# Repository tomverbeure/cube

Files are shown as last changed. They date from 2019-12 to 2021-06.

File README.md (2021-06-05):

# LED Cube with Cisco Controller and Pixel Purse LED Panels

This repo needs a bit of cleanup for general public consumption,
but it had all the assets for my LED cube that’s built from
[Project MC2 Pixel Purse LED panels](https://tomverbeure.github.io/2019/10/03/Pixel-Purse.html) 
and a [Cisco HWIC-3G-CDMA modem](https://tomverbeure.github.io/2019/11/11/Cisco-HWIC-3G-CDMA.html).

I gave a talk about this project at BangBangCon West 2020: here are
the [video](https://www.youtube.com/watch?v=0tBU5-lJYmU) and [slides](https://docs.google.com/presentation/d/1FYmVh-brx6SpZoJmzuIXrNegWdtriQ9k38EbrvDupg8) of the talk.

I also wrote a [blog post](https://tomverbeure.github.io/2021/05/16/Pixel-Purse-LED-Cube.html)
about this project.

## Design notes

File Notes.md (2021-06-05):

## Current Measurements:

* 3.3V

0:

* All LEDs off: 0.6A

255:

* All LEDs red: 6.6A
* All LEDs green: 3.6A
* All LEDs blue: 2.8A

* All LEDs red + green: 6.8A
* All LEDs red + blue: 6.5A
* All LEDs green + blue: 4.2A

* All LEDs green + green + blue: 7.8A

128: (with gamma!)

* All LEDs red: 2.2A
* All LEDs green: 1.3A
* All LEDs blue: 1.2A

* All LEDs red + green: 2.5A
* All LEDs red + blue: 2.3A
* All LEDs green + blue: 1.6A

* All LEDs green + green + blue: 2.4A

64: (with gamma!)

* All LEDs red: 1.0A
* All LEDs green: 0.8A
* All LEDs blue: 0.7A

* All LEDs red + green: 1.1A
* All LEDs red + blue:
* All LEDs green + blue: 

* All LEDs green + green + blue: 1.1A

## LED Addressing

### LED Memory Physical Address map

LED mem has 2 buffers (for double-buffered rendering).
Each buffer has a size of 6 * 32 * 32 = 6144 words, so the total LED memory is 12288 words.

In LED mem, each side of the cube has a rectangle assigned to them.

The sides are numbered as follows:
   
```
    +---+
    | 4 |     
+---+---+---+---+
| 0 | 1 | 2 | 3 |
+---+---+---+---+
    | 5 |     
    +---+
```

Within a buffer, addressing is as follows:

* start address of each side is `side_nr * 32 * 32`
* start address corresponds to the top-left of each square above
* the pitch of each side is the same as the number of columns.

The corresponding naming convention: left, front, right, back, top, bottom.

```
    +---+
    | T |     
+---+---+---+---+
| L | F | R | Ba|
+---+---+---+---+
    | Bo|     
    +---+
```

The Hub75Streamer block has a `PANEL_INFO` registers that contains all the information to
translate from the LED mem addressing. If panels are rotated, it can compensate for that.

### LED Memory Locial Address Maps

To make life for the CPU easier, there are also logical address maps, which are
designed such that there is an intuitive overflow behavior wrt neighboring tile.

There is one logical map for each 'infinite ring', where, if you continue in the same
primary direction, you end up in the same place as before in a logical way.

Here is one such example:

```
+---+---+---+---+---+---+
| T | T | T | T | T | T |   
+---+---+---+---+---+---+
| L | F | R | Ba| L | F |
+---+---+---+---+---+---+
| Bo| Bo| Bo| Bo| Bo| Bo|
+---+---+---+---+---+---+
```

In this case, the ring consists of tile L-F-R-B. T and B are considered non-ring
overflow tiles.

When you start on the left side and keep in increasing the X coordinate, you'll wrap around
the cube and end up in the same place after 4 side.

The image above is laid out on a rectangular logical address map, with a pitch that is at least
6 wide. But it's easier to make it 8 wide, so it will look a bit like this:

```
+---+---+---+---+---+---+---+---+
| T | T | T | T | T | T | T | T |
+---+---+---+---+---+---+---+---+
| L | F | R | Ba| L | F | R | Ba|
+---+---+---+---+---+---+---+---+
| Bo| Bo| Bo| Bo| Bo| Bo| Bo| Bo|
+---+---+---+---+---+---+---+---+
```

With the arrangement above, you can blit any image that is 32 pixels height and up to
5 sides wide at any starting point of the ring and have correct roll-over behavior.
Since it makes no sense to have a image that's more than 4 sides wide (because the right
would overwrite the left), that's fine.

For the case above, the top and the bottom tiles will have different overflow
behavior for each for the 4 members of the ring. For example if you are in L and
you go up until you roll over into tile T, then the L(X,Y) coordinate converts into
T(X, Y). However, if you in F and you do the same thing, then F(X,Y) converts
into T(32-Y,X).

Here are different rings: 

F-Bo-Ba-T:

```
+---+---+---+---+---+---+---+---+
| R | R | R | R | R | R | R | R |
+---+---+---+---+---+---+---+---+
| F | Bo| Ba| T | F | Bo| Ba| T |
+---+---+---+---+---+---+---+---+
| L | L | L | L | L | L | L | L |
+---+---+---+---+---+---+---+---+
```

L-Bo-R-T:

```
+---+---+---+---+---+---+---+---+
| Ba| Ba| Ba| Ba| Ba| Ba| Ba| Ba|
+---+---+---+---+---+---+---+---+
| L | Bo| R | T | L | Bo| R | T |
+---+---+---+---+---+---+---+---+
| F | F | F | F | F | F | F | F |
+---+---+---+---+---+---+---+---+
```

Calculation for:

| L | F | R | Ba| L | F | R | Ba|

Given an address for a particular ring:

```
strip_size = 16 * 32 * 32
side_size  = 32 * 32

strip_y_nr = addr / strip_size
strip_x_nr = (addr % strip_size) / side_size

strip_class = [ L, F, R, Ba ][strip_x_nr & 3]
if (strip_y_nr == 0) 
    side_nr = T
    orient_class = { 
                     L  -> (32-X, Y),
                     F  -> (X, Y),  
                     R  -> (32-Y, X),
                     Ba -> (32-X, Y)
                   }[strip_class]
                     
else if (strip_y_nr == 1) 
    side_nr = strip_class
    orient_class = (X,Y)

else if (strip_y_nr == 2)
    side_nr = Bo
    orient_class = { 
                     L  -> (32-X, Y),
                     F  -> (X, Y),  
                     R  -> (32-Y, X),
                     Ba -> (32-X, Y)
                   }[strip_class]

led_mem_addr = (side_nr * 32 * 32) + orient_class[1] * 32 + orient_class[0]
```

Each ring occupies 8 x 3 = 24 sides, but we allocate 32 sides for that.
That gives 32 * 32 * 32 = 32k addresses per ring.
There are 3 rings, so we need 98k local addresses.

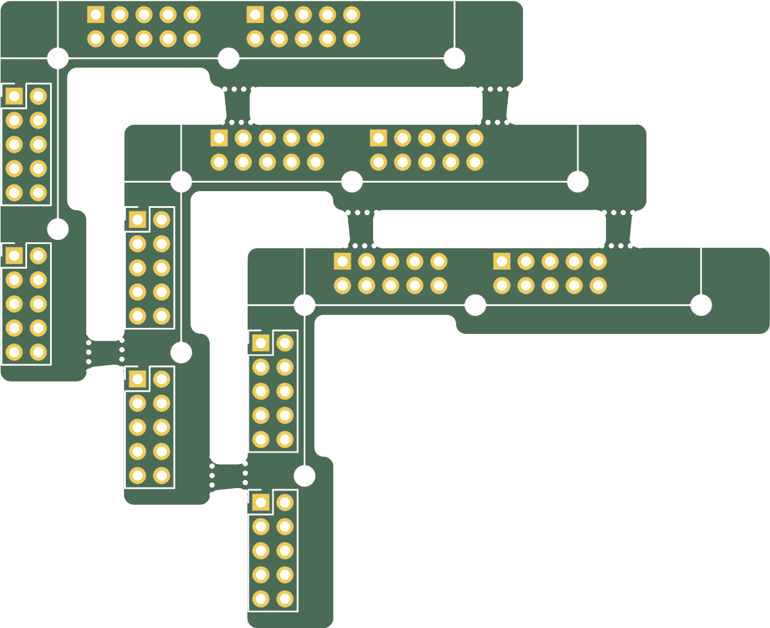
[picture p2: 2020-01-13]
pcbs/frame_corners/panelized/upload1/Untitled_Combined_Top.png

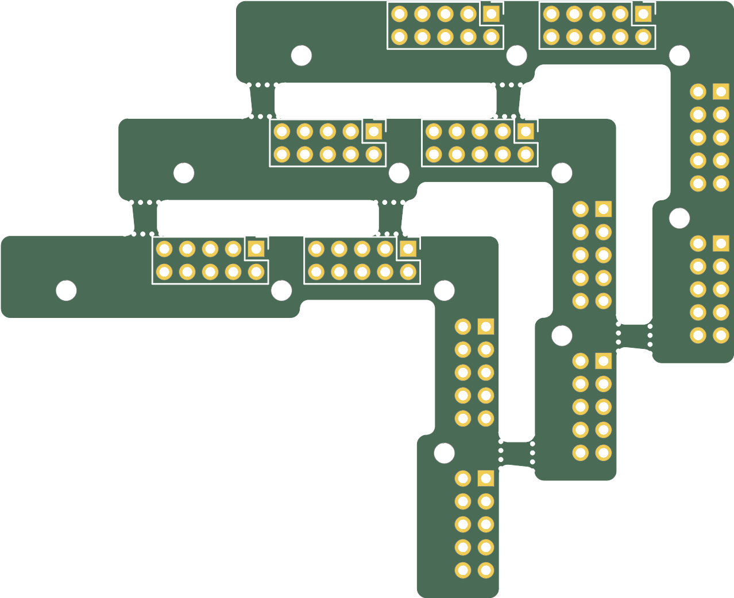
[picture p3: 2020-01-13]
pcbs/frame_corners/panelized/upload1/Untitled_Combined_Bottom.png

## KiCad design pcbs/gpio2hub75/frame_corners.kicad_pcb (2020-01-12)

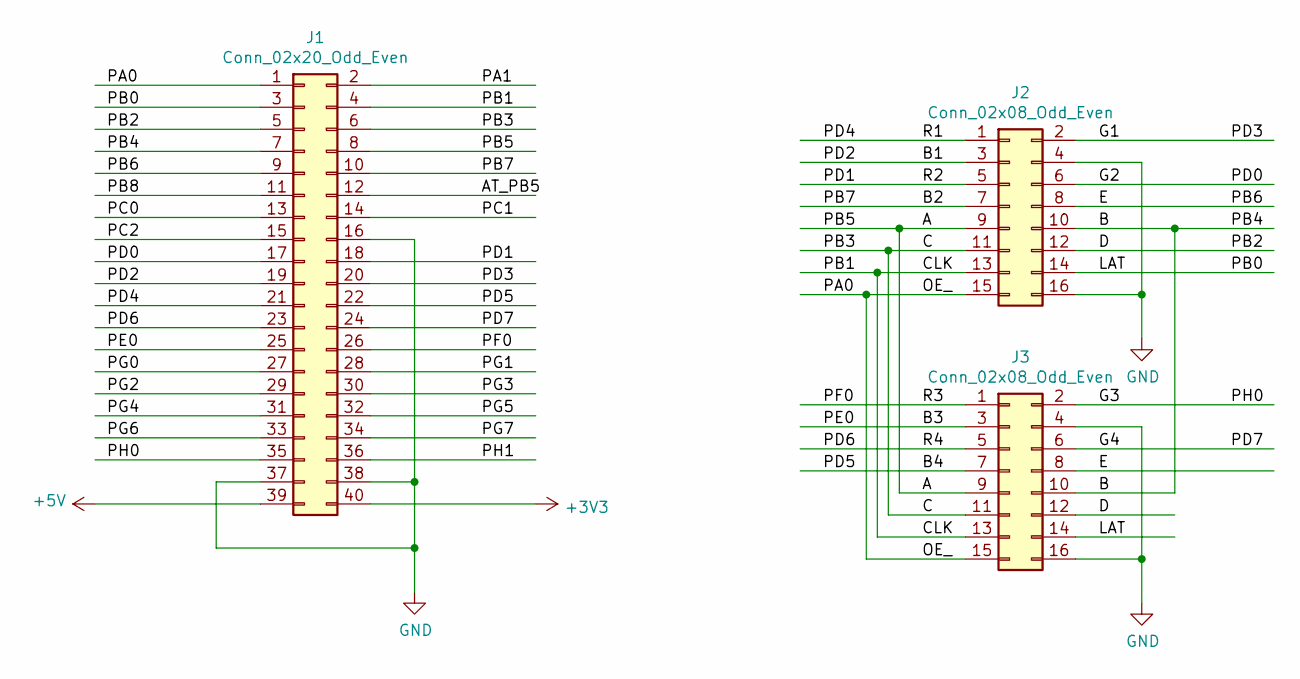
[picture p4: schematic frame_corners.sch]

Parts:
J1: Conn_02x20_Odd_Even; PinSocket_2x20_P2.54mm_Horizontal
J2, J3: Conn_02x08_Odd_Even; PinHeader_2x08_P2.54mm_Vertical

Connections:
+3V3: J1.40
+5V: J1.39
/A: J1.8, J2.9, J3.9
/AT_PB5: J1.12
/B: J1.7, J2.10, J3.10
/B1: J1.19, J2.3
/B2: J1.10, J2.7
/B3: J1.25, J3.3
/B4: J1.22, J3.7
/C: J1.6, J2.11, J3.11
/CLK: J1.4, J2.13, J3.13
/D: J1.5, J2.12, J3.12
/E: J1.9, J2.8, J3.8
/G1: J1.20, J2.2
/G2: J1.17, J2.6
/G3: J1.35, J3.2
/G4: J1.24, J3.6
/LAT: J1.3, J2.14, J3.14
/OE_: J1.1, J2.15, J3.15
/PA1: J1.2
/PB8: J1.11
/PC0: J1.13
/PC1: J1.14
/PC2: J1.15
/PD1: J1.18, J2.5
/PD4: J1.21, J2.1
/PD6: J1.23, J3.5
/PF0: J1.26, J3.1
/PG0: J1.27
/PG1: J1.28
/PG2: J1.29
/PG3: J1.30
/PG4: J1.31
/PG5: J1.32
/PG6: J1.33
/PG7: J1.34
/PH1: J1.36
GND: J1.16, J1.37, J1.38, J2.4, J2.16, J3.4, J3.16

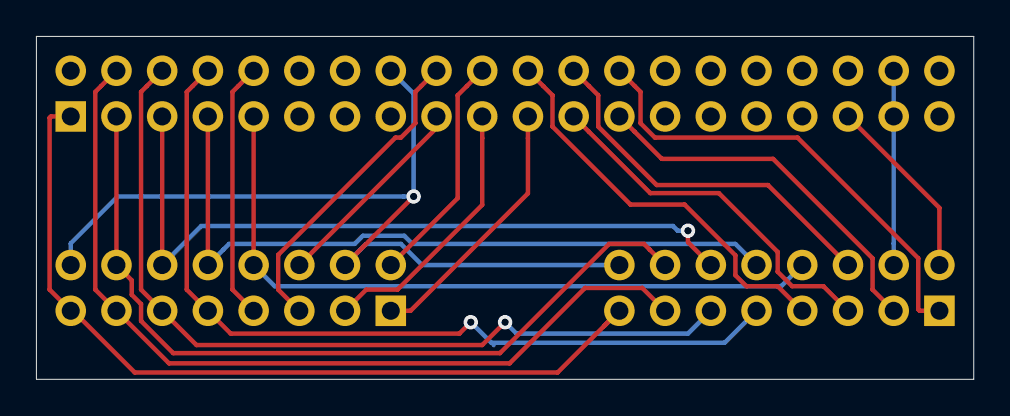
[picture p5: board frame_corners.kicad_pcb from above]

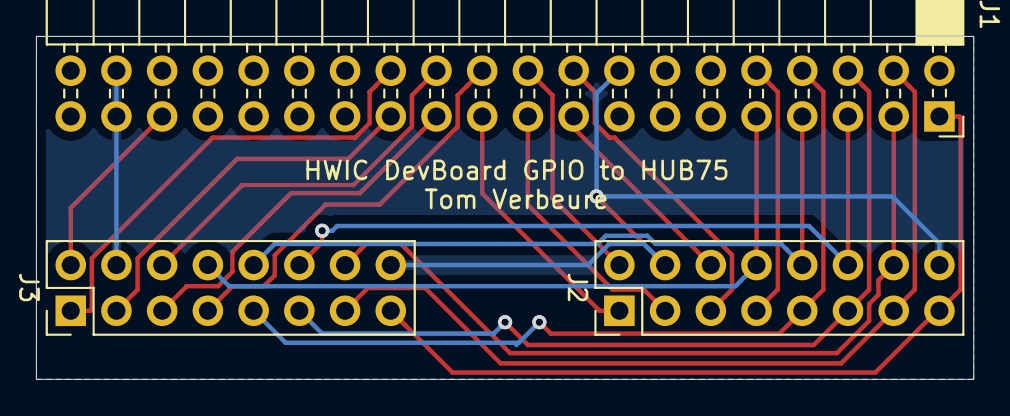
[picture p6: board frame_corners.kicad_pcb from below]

Board: 2 copper layers, 52.1 x 19.1 mm, 3 parts (3 on the bottom side), 21 nets.

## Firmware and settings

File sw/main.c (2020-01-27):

#include <stdint.h>

#include "reg.h"
#include "top_defines.h"
//#include "led_render.h"
#include "hub75_streamer.h"

#include "../movie/palette.h"
#include "../movie/ricks_compr.h"

static inline uint32_t rdcycle(void) {
    uint32_t cycle;
    asm volatile ("rdcycle %0" : "=r"(cycle));
    return cycle;
}

static inline int nop(void) {
    asm volatile ("addi x0, x0, 0");
    return 0;
}

void wait(int cycles)
{
#if 1
    volatile int cnt = 0;

    for(int i=0;i<cycles/20;++i){
        ++cnt;
    }
#else
    int start;

    start = rdcycle();
    while ((rdcycle() - start) <= cycles);
#endif
}


uint16_t pacman_closed[11] = {
    0b00011111000,
    0b00111111100,
    0b01111111110,
    0b11111111111,
    0b11111111111,
    0b11111111111,
    0b11111111111,
    0b11111111111,
    0b01111111110,
    0b00111111100,
    0b00011111000,
};

uint16_t pacman_open[11] = {
    0b00011111000,
    0b00111111100,
    0b01111111110,
    0b00011111111,
    0b00000111111,
    0b00000001111,
    0b00000111111,
    0b00011111111,
    0b01111111110,
    0b00111111100,
    0b00011111000,
};

uint16_t pacman_test[11] = {
    0b10000000000,
    0b11000000000,
    0b10100000000,
    0b10010000000,
    0b10001000000,
    0b10000100000,
    0b10000010000,
    0b10000001000,
    0b10000000100,
    0b10000000010,
    0b10000000001,
};

uint32_t ghost_left_0[14] = {
    0b0000000000010101010000000000,
    0b0000000101010101010101000000,
    0b0000010101010101010101010000,
    0b0001010101010101010101010100,
    0b0001010111110101010111110100,
    0b0001011111111101011111111100,
    0b0101011111101001011111101001,
    0b0101011111101001011111101001,
    0b0101010111110101010111110101,
    0b0101010101010101010101010101,
    0b0101010101010101010101010101,
    0b0101010101010101010101010101,
    0b0101010100010101010001010101,
    0b0001010000000101000000010100,
};

uint32_t ghost_left_1[14] = {
    0b0000000000010101010000000000,
    0b0000000101010101010101000000,
    0b0000010101010101010101010000,
    0b0001010101010101010101010100,
    0b0001010111110101010111110100,
    0b0001011111111101011111111100,
    0b0101011111101001011111101001,
    0b0101011111101001011111101001,
    0b0101010111110101010111110101,
    0b0101010101010101010101010101,
    0b0101010101010101010101010101,
    0b0101010101010101010101010101,
    0b0101000101010000010101000101,
    0b0100000001010000010100000001,
};


uint32_t ghost_up_0[14] = {
    0b0000000000010101010000000000,
    0b0000001010010101011010000000,
    0b0000111010110101111010110000,
    0b0001111111110101111111110100,
    0b0001111111110101111111110100,
    0b0001011111010101011111010100,
    0b0101010101010101010101010101,
    0b0101010101010101010101010101,
    0b0101010101010101010101010101,
    0b0101010101010101010101010101,
    0b0101010101010101010101010101,
    0b0101010101010101010101010101,
    0b0101010100010101010001010101,
    0b0001010000000101000000010100,
};

uint32_t ghost_up_1[14] = {
    0b0000000000010101010000000000,
    0b0000001010010101011010000000,
    0b0000111010110101111010110000,
    0b0001111111110101111111110100,
    0b0001111111110101111111110100,
    0b0001011111010101011111010100,
    0b0101010101010101010101010101,
    0b0101010101010101010101010101,
    0b0101010101010101010101010101,
    0b0101010101010101010101010101,
    0b0101010101010101010101010101,
    0b0101010101010101010101010101,
    0b0101000101010000010101000101,
    0b0100000001010000010100000001,
};

uint32_t ghost_down_0[14] = {
    0b0000000000010101010000000000,
    0b0000000101010101010101000000,
    0b0000010101010101010101010000,
    0b0001010101010101010101010100,
    0b0001011111010101011111010100,
    0b0001111111110101111111110100,
    0b0101111111110101111111110101,
    0b0101111010110101111010110101,
    0b0101011010010101011010010101,
    0b0101010101010101010101010101,
    0b0101010101010101010101010101,
    0b0101010101010101010101010101,
    0b0101010100010101010001010101,
    0b0001010000000101000000010100,
};

uint32_t ghost_down_1[14] = {
    0b0000000000010101010000000000,
    0b0000000101010101010101000000,
    0b0000010101010101010101010000,
    0b0001010101010101010101010100,
    0b0001011111010101011111010100,
    0b0001111111110101111111110100,
    0b0101111111110101111111110101,
    0b0101111010110101111010110101,
    0b0101011010010101011010010101,
    0b0101010101010101010101010101,
    0b0101010101010101010101010101,
    0b0101010101010101010101010101,
    0b0101000101010000010101000101,
    0b0100000001010000010100000001,
};



uint32_t ghost_scared_0[14] = {
    0b0000000000010101010000000000,
    0b0000000101010101010101000000,
    0b0000010101010101010101010000,
    0b0001010101010101010101010100,
    0b0001010101010101010101010100,
    0b0001010111110101111101010100,
    0b0101010111110101111101010101,
    0b0101010101010101010101010101,
    0b0101010101010101010101010101,
    0b0101111101011111010111110101,
    0b0111010111110101111101011101,
    0b0101010101010101010101010101,
    0b0101000101010000010101000101,
    0b0100000001010000010100000001,
};


uint32_t cherry[12] = {
    0b000000000000000000001010,
    0b000000000000000010101010,
    0b000000000000101000100000,
    0b000000000010000000100000,
    0b000101011000000010000000,
    0b010101100101001000000000,
    0b010101010100011001010000,
    0b011101010001011001010100,
    0b010111010001010101010100,
    0b000101010001110101010100,
    0b000000000001011101010100,
    0b000000000000010101010000,
};

uint16_t dot_small[2] = {
    0b11,
    0b11,
};

uint16_t dot_large[8] = {
    0b00111100,
    0b01111110,
    0b11111111,
    0b11111111,
    0b11111111,
    0b11111111,
    0b01111110,
    0b00111100,
};

uint32_t mario_ground[3] = {
    0b01111111111111111110011111111101,
    0b11010101010101010110110101010110,
    0b11010101010101010110111001010110
};

uint32_t mario_ground_colors[4] = { 0x000000, 0x1556d0, 0x000000, 0xc1c2f7 };

uint32_t mario_sky_color = 0xff8f58;


uint32_t mario_walk_0[16] = {
    0b00000000001010101010000000000000,
    0b00000000101010101010101010000000,
    0b00000000010101111101110000000000,
    0b00000001110111111101111111000000,
    0b00000001110101111111011111110000,
    0b00000001011111111101010101000000,
    0b00000000001111111111111100000000,
    0b00000101010110100101000000000000,
    0b11110101010110101001010111111100,
    0b11111100010110111010100101111100,
    0b11110000101010101010100000010000,
    0b00000010101010101010101001010000,
    0b00001010101010101010101001010000,
    0b00010110101000000010101001010000,
    0b00010101000000000000000000000000,
    0b00000101010000000000000000000000,
};

uint32_t mario_walk_1[16] = {
    0b00000000001010101010000000000000,
    0b00000000101010101010101010000000,
    0b00000000010101111101110000000000,
    0b00000001110111111101111111000000,
    0b00000001110101111111011111110000,
    0b00000001011111111101010101000000,
    0b00000000001111111111111100000000,
    0b00000000010110010101000000000000,
    0b00000001010101101001010000000000,
    0b00000001010110101110101100000000,
    0b00000001010101101010101000000000,
    0b00000010010111111110101000000000,
    0b00000000100111111010100000000000,
    0b00000000001010100101010000000000,
    0b00000000000101010101010100000000,
    0b00000000000101010100000000000000,
};

uint32_t mario_walk_2[16] = {
    0b00000000000000000000000000000000,
    0b00000000000010101010100000000000,
    0b00000000001010101010101010100000,
    0b00000000000101011111011100000000,
    0b00000000011101111111011111110000,
    0b00000000011101011111110111111100,
    0b00000000010111111111010101010000,
    0b00000000000011111111111111000000,
    0b00000000000101010110010011000000,
    0b00000000110101010101011111110000,
    0b00000011111001010101011111000000,
    0b00000001011010101010101000000000,
    0b00000001101010101010101000000000,
    0b00000101101010001010100000000000,
    0b00000100000000010101000000000000,
    0b00000000000000010101010000000000,
};


uint32_t mario_colors[4] = { 0x000000, 0x106d8a, 0x053bec, 0x3d9fff };


uint32_t pac_color = 0x36fffe;

uint32_t ghost_pink_colors[4]    = { 0x000000, 0xcb98ff, 0xff0000, 0xffffff };
uint32_t ghost_cyan_colors[4]    = { 0x000000, 0xfffe2c, 0xff0000, 0xffffff };
uint32_t ghost_red_colors[4]     = { 0x000000, 0x0711ff, 0xff0000, 0xffffff };
uint32_t ghost_orange_colors[4]  = { 0x000000, 0x42cfff, 0xff0000, 0xffffff };
uint32_t ghost_scared_colors[4]  = { 0x000000, 0xfb1313, 0x000000, 0x42cfff };

uint32_t cherry_colors[4]        = { 0x000000, 0x0711ff, 0x5599de, 0xffffff };

uint32_t border_color = 0xfb0022;

uint32_t dot_color = 0x92b1f8;


#define WAIT_CYCLES 4000000

void led_mem_wr(int buffer_nr, int side, int x, int y, unsigned char r, unsigned char g, unsigned char b)
{
        MEM_WR(LED_MEM, buffer_nr * 6 * 32 * 32 + side * 32 * 32 + y*32 + x, r | (g<<8) | (b<<16));
}

void led_mem_fill(int buffer_nr, unsigned char r, unsigned char g, unsigned char b)
{
    for(int side = 0; side < 6; ++side){
	    for(int row=0;row<32;++row){
	        for(int col=0;col<32;++col){
	            led_mem_wr(buffer_nr, side, col, row, r, g, b);
	        }
	    }
    }
}

void led_mem_clear(int buffer_nr)
{
    led_mem_fill(buffer_nr, 0, 0, 0);
}

void led_mem_effect(int buffer_nr)
{
    unsigned char r,g,b;

    for(r=0;r<255;++r){
        for(g=0;g<255;++g){
            for(b=0;b<255;++b){
                led_mem_fill(buffer_nr, r,g,b);
            }
        }
    }
}

void led_mem_stripes(int buffer_nr)
{
    for(int side = 0; side < 6; ++side){
	    for(int row=0;row<32;++row){
	        for(int col=0;col<32;++col){
	            led_mem_wr(buffer_nr, side, col, row, 
	                            (col % 3) == 0 ? 255 : 0, 
	                            (col % 3) == 1 ? 255 : 0, 
	                            (col % 3) == 2 ? 255 : 0);
	        }
	    }
    }
}

void led_mem_stripes_rick()
{

    for(int frame_nr = 0; frame_nr < 16; ++frame_nr){

        unsigned char *ptr = ricks_compr_bin + frame_nr * 32 * 23;

        for(int row=0; row<23; ++row){
            for(int col=0;col<32;col+=2){
                if (col == frame_nr*2){
                    ptr[row * 32 + col] = 10;
                }
                else{
                    ptr[row * 32 + col] = 0;
                }
            }
        }
    }
}

void led_mem_rows(int buffer_nr)
{
    for(int side=0; side<6; side++){
	    for(int row=0;row<32;++row){
	        for(int col=0;col<32;++col){
	            if (col<10){
	                led_mem_wr(buffer_nr, side, col, row, row*7, 0, 0);
	            } 
	            else if (col<20){
	                led_mem_wr(buffer_nr, side, col, row, 0, row*7, 0);
	            }
	            else if (col<30){
	                led_mem_wr(buffer_nr, side, col, row, 0, 0, row*7);
	            }
	            else{
	                led_mem_wr(buffer_nr, side, col, row, 0, row*7, row*7);
	            }
	        }
	    }
    }
}

void led_mem_rick(int buffer_nr, int frame_nr)
{

    for(int side = 0; side < 6; ++side){

        int frame_nr_adj = (frame_nr + side) % 16;
        unsigned char *ptr = ricks_compr_bin + frame_nr_adj * (32/2) * 23;

	    for(int row=0; row<32; ++row){
	        for(int col=0;col<32;col+=2){
	            if (row < 4 || row >= 27){
	                led_mem_wr(buffer_nr, side, col, row, side == 0 || side == 3 ? 32 : 0, side == 1 || side == 4 ? 32 : 0 , side == 2 || side == 5 ? 32 : 0);
	            }
	            else{
	                unsigned char val = *ptr;

	                led_mem_wr(buffer_nr, side, col, row, 
	                                palette_bin[(val & 15) * 3],
	                                palette_bin[(val & 15) * 3 + 1],
	                                palette_bin[(val & 15) * 3 + 2]);

	                led_mem_wr(buffer_nr, side, col+1, row, 
	                                palette_bin[(val>>4) * 3],
	                                palette_bin[(val>>4) * 3 + 1],
	                                palette_bin[(val>>4) * 3 + 2]);
	                ++ptr;
	            }
	
	        }
	    }
    }
}

void render_bitmap_1bpp(uint16_t *bitmap, uint32_t color, int size_x, int size_y, int buffer_nr, e_hub75_ring ring, int pos_x, int pos_y)
{
    for(int y=0; y<size_y;++y){
        for(int x=0; x<size_x;++x){
                //uint32_t bit = (bitmap[y] >> (size_x-1-x)) & 1;
                uint32_t bit = (bitmap[y] >> (x)) & 1;
                if (!bit)
                    continue;

                uint32_t log_addr = ring * HUB75S_RING_SIZE 
                                    + ((pos_y+y) + HUB75S_SIDE_HEIGHT) * HUB75S_STRIP_WIDTH 
                                    + (pos_x+x);
                    
                uint32_t phys_addr = hub75s_calc_phys_addr(buffer_nr, log_addr);

                MEM_WR(LED_MEM, phys_addr, color);
        }
    }
}

void render_bitmap_2bpp(uint32_t *bitmap, uint32_t *colors, int size_x, int size_y, int buffer_nr, e_hub75_ring ring, int pos_x, int pos_y)
{
    for(int y=0; y<size_y;++y){
        for(int x=0; x<size_x;++x){
                //uint32_t bit = (bitmap[y] >> (size_x-1-x)) & 1;
                uint32_t bits = (bitmap[y] >> (2*size_x-2 - 2*x)) & 3;
                if (bits == 0)
                    continue;

                uint32_t log_addr = ring * HUB75S_RING_SIZE 
                                    + ((pos_y+y) + HUB75S_SIDE_HEIGHT) * HUB75S_STRIP_WIDTH 
                                    + (pos_x+x);
                    
                uint32_t phys_addr = hub75s_calc_phys_addr(buffer_nr, log_addr);

                uint32_t color = colors[bits];

                MEM_WR(LED_MEM, phys_addr, color);
        }
    }
}

void play_rick(int total_nr_frames)
{
    uint32_t movie_frame = 0;
    uint32_t scratch_buf = 1;

    int pos_x = 0;

    uint32_t start_frame = REG_RD(HUB75S_FRAME_CNTR);

    while(REG_RD(HUB75S_FRAME_CNTR) < start_frame + total_nr_frames){
        led_mem_clear(scratch_buf);
        led_mem_rick(scratch_buf, movie_frame);
        movie_frame = (movie_frame + 1) % 16;

        pos_x = (pos_x + 1) % (4 * HUB75S_SIDE_WIDTH);

        uint32_t prev_frame_cntr = REG_RD(HUB75S_FRAME_CNTR);
        while(REG_RD(HUB75S_FRAME_CNTR) < prev_frame_cntr + 14) ;

        REG_WR_FIELD(HUB75S_CONFIG, BUFFER_NR, scratch_buf);
        while(REG_RD_FIELD(HUB75S_STATUS, CUR_BUFFER_NR) != scratch_buf) 
            ;

        scratch_buf ^= 1;
    }

}

void play_pacman(int total_nr_frames)
{
    uint32_t scratch_buf = 1;

    int pos_x = 0;
    int pos_y = 10;

    uint32_t start_frame = REG_RD(HUB75S_FRAME_CNTR);

    while(REG_RD(HUB75S_FRAME_CNTR) < start_frame + total_nr_frames){

        led_mem_clear(scratch_buf);

        uint32_t *current_ghost = ghost_left_0;
        uint16_t *current_pac   = pacman_open;
        
        if (REG_RD(HUB75S_FRAME_CNTR) % 20 > 10){
            current_ghost = ghost_left_1;
            current_pac   = pacman_closed;
        }

        render_bitmap_1bpp(current_pac, pac_color, 11, 11, scratch_buf, RING_LFRBa, (pos_x) % (4*HUB75S_SIDE_WIDTH), pos_y);

        int chase_dist = 20;
        int ghost_delta = 12;

        render_bitmap_2bpp(current_ghost,   ghost_pink_colors,    14, 14, scratch_buf, RING_LFRBa, (pos_x - chase_dist - 0 * ghost_delta) % (4*HUB75S_SIDE_WIDTH), pos_y-2);
        render_bitmap_2bpp(current_ghost,   ghost_red_colors,     14, 14, scratch_buf, RING_LFRBa, (pos_x - chase_dist - 1 * ghost_delta) % (4*HUB75S_SIDE_WIDTH), pos_y-2);
        render_bitmap_2bpp(current_ghost,   ghost_orange_colors,  14, 14, scratch_buf, RING_LFRBa, (pos_x - chase_dist - 2 * ghost_delta) % (4*HUB75S_SIDE_WIDTH), pos_y-2);
        render_bitmap_2bpp(current_ghost,   ghost_cyan_colors,    14, 14, scratch_buf, RING_LFRBa, (pos_x - chase_dist - 3 * ghost_delta) % (4*HUB75S_SIDE_WIDTH), pos_y-2);

        render_bitmap_2bpp(ghost_scared_0, ghost_scared_colors,  14, 14, scratch_buf, RING_LFRBa, (pos_x + 30) % (4*HUB75S_SIDE_WIDTH), pos_y-2);

        render_bitmap_2bpp(cherry, cherry_colors, 12, 12, scratch_buf, RING_LFRBa, 10 + HUB75S_SIDE_WIDTH, 10-HUB75S_SIDE_WIDTH);

        pos_x = (pos_x + 1) % (4 * HUB75S_SIDE_WIDTH);

        uint32_t prev_frame_cntr = REG_RD(HUB75S_FRAME_CNTR);
        while(REG_RD(HUB75S_FRAME_CNTR) < prev_frame_cntr + 6) ;

        REG_WR_FIELD(HUB75S_CONFIG, BUFFER_NR, scratch_buf);
        while(REG_RD_FIELD(HUB75S_STATUS, CUR_BUFFER_NR) != scratch_buf) 
            ;

        scratch_buf ^= 1;
    }
}

void play_mario(int total_nr_frames)
{
    uint32_t scratch_buf = 1;

    int pos_x = 0;
    int pos_y = 10;

    uint32_t start_frame = REG_RD(HUB75S_FRAME_CNTR);

    while(REG_RD(HUB75S_FRAME_CNTR) < start_frame + total_nr_frames){

        led_mem_fill(scratch_buf, (mario_sky_color & 255) * 3/4, ((mario_sky_color >> 8) & 255) * 3/4, (mario_sky_color >> 16) *3/4); 

        int stride = (REG_RD(HUB75S_FRAME_CNTR) % 21)/7;

        uint32_t *current_mario = stride == 0 ? mario_walk_0 :
                                  stride == 1 ? mario_walk_1 :
                                                mario_walk_2 ;


        /*
        if ((pos_x & 31) < 15){
            int q = ((pos_x & 15) - 8)*2/3;
            pos_y = 14-q*q;
        }
        else{
            pos_y = 14;
        }
        */

        pos_y = 14;

        for(int i=0;i<256;i+=16){
            render_bitmap_2bpp(mario_ground, mario_ground_colors, 16, 3, scratch_buf, RING_LFRBa, i % (4*HUB75S_SIDE_WIDTH), 29);
        }

        render_bitmap_2bpp(current_mario,   mario_colors,    16, 16, scratch_buf, RING_LFRBa, (pos_x) % (4*HUB75S_SIDE_WIDTH), pos_y);

        pos_x = (pos_x + 1) % (4 * HUB75S_SIDE_WIDTH);

        uint32_t prev_frame_cntr = REG_RD(HUB75S_FRAME_CNTR);
        while(REG_RD(HUB75S_FRAME_CNTR) < prev_frame_cntr + 6) ;

        REG_WR_FIELD(HUB75S_CONFIG, BUFFER_NR, scratch_buf);
        while(REG_RD_FIELD(HUB75S_STATUS, CUR_BUFFER_NR) != scratch_buf) 
            ;

        scratch_buf ^= 1;
    }
}


int main() {

    hub75s_config();
    hub75s_start();

    REG_WR(LED_DIR, 0xff);

    hub75s_dim(0x40, 0x40, 0x40);

    while(1){
        play_rick(120 * 3);
        play_pacman(120 * 15);
        play_mario(120 * 6);
    }
}

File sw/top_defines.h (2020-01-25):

#define TIMER_ADDR                  0x00000000

#define LED_READ_ADDR               0x00010000
#define LED_WRITE_ADDR              0x00010004
#define	LED_DIR_ADDR                0x00010008

#define LED_MEM_ADDR                0x00020000

#define HUB75S_CONFIG_ADDR    0x00030000

#define HUB75S_CONFIG_ENABLE_FIELD_START                0
#define HUB75S_CONFIG_ENABLE_FIELD_LENGTH               1

#define HUB75S_CONFIG_START_FIELD_START                 1
#define HUB75S_CONFIG_START_FIELD_LENGTH                1

#define HUB75S_CONFIG_AUTO_RESTART_FIELD_START          2
#define HUB75S_CONFIG_AUTO_RESTART_FIELD_LENGTH         1

#define HUB75S_CONFIG_BUFFER_NR_FIELD_START             4
#define HUB75S_CONFIG_BUFFER_NR_FIELD_LENGTH            1


#define HUB75S_STATUS_ADDR    0x00030004

#define HUB75S_STATUS_CUR_PANEL_NR_FIELD_START          0
#define HUB75S_STATUS_CUR_PANEL_NR_FIELD_LENGTH         4

#define HUB75S_STATUS_CUR_ROW_NR_FIELD_START            8
#define HUB75S_STATUS_CUR_ROW_NR_FIELD_LENGTH           5

#define HUB75S_STATUS_CUR_BIT_NR_FIELD_START            16
#define HUB75S_STATUS_CUR_BIT_NR_FIELD_LENGTH           3

#define HUB75S_STATUS_CUR_BUFFER_NR_FIELD_START         31
#define HUB75S_STATUS_CUR_BUFFER_NR_FIELD_LENGTH        1

#define HUB75S_FRAME_CNTR_ADDR  0x00030008

#define HUB75S_RGB_DIM_ADDR  0x0003000c

#define HUB75S_PANEL_INFOS_ADDR                         0x0030100

#define HUB75S_PANEL_INFO_X_SIZE                        0x40

#define HUB75S_PANEL_INFO_X_MISC_ADDR                   0x00
#define HUB75S_PANEL_INFO_X_MEM_ADDR_START_PH0_ADDR     0x04
#define HUB75S_PANEL_INFO_X_MEM_ADDR_START_PH1_ADDR     0x08
#define HUB75S_PANEL_INFO_X_MEM_ADDR_COL_MUL_ADDR       0x0c
#define HUB75S_PANEL_INFO_X_MEM_ADDR_ROW_MUL_ADDR       0x10

#define HUB75S_PI_REG_WR(idx, reg_name, wr_data)        (*( (volatile uint32_t *)(0x80000000 | (HUB75S_PANEL_INFOS_ADDR + (HUB75S_PANEL_INFO_X_SIZE * idx) + HUB75S_PANEL_INFO_X_##reg_name##_ADDR) )) = (wr_data))

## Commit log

2019-12-09 Small system from LedMatrix project.
2019-12-09 LedMatrix -> Cube
2019-12-29 Expand columns past 64 for chained panels.
2019-12-29 Clean blanking, longer LAT pulse.
    Increase column scanning phase by 3 clock cycles so that BLANK/OE_
    and LAT can be switched on and off in their own clock cycles for
    a clean image.
2019-12-29 Just make LEDs blink again to prove that CPU is working.
2019-12-30 Separate Hub75 driver from Hub75 pixel generator.
2019-12-30 Issue DMA request. WIP.
2019-12-31 APB DMA FSM. WIP.
2020-01-02 Move LedMem to CubeTop. WIP.
2020-01-02 Wire up LedMem to Hub75Streamer.
2020-01-02 Stream LED data from RAM.
2020-01-05 Double buffered LedMem.
2020-01-05 Animated rick on LED. Looks terrible...
2020-01-10 frame_corners checkpoint.
    [frame_corners.kicad_pcb, frame_corners.sch]
2020-01-11 mechanical -> pcbs
    [frame_corners.kicad_pcb, frame_corners.sch]
2020-01-11 Remove GPIO 2 HUB75 board from frame corners.
    [frame_corners.kicad_pcb, frame_corners.sch]
2020-01-11 First version
    [frame_corners-B_Cu.gbr, frame_corners-B_Mask.gbr, frame_corners-B_Paste.gbr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]
2020-01-11 Minor changes.
    [frame_corners.kicad_pcb]
2020-01-12 gpio2hub75 board
    [frame_corners-B_Cu.gbr, frame_corners-B_Mask.gbr, frame_corners-B_Paste.gbr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]
2020-01-13 Panelization with https://gitlab.com/dren.dk/kicad-util
    [combined.GKO, combined.drl, combined.gbl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]
2020-01-16 Move towards SW LED renderer.
2020-01-24 Add frame counter.
2020-01-24 Use frame counter.
2020-01-24 Fix panel info for right connector panels.
    [main.c]
2020-01-24 Fix one more panel.
    [main.c]
2020-01-25 Switch back to 120Hz.
2020-01-25 Fix orientation of all faces!
    [main.c]
2020-01-25 Power measurements.
2020-01-25 Different sides read from different led_mem.
